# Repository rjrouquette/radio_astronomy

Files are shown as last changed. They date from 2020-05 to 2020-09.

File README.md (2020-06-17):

# Radio Astronomy
This project is an attempt at an SDR DAS phased-array radio astronomy system.  The intent is to produce a flexible and scalable system that can be easily repurposed with minimal additional cost.

## Digitizer
The digitizer board employs a direct IF to digital conversion toplogy to reduce the 62.5 MHz IF input into I+Q baseband data.

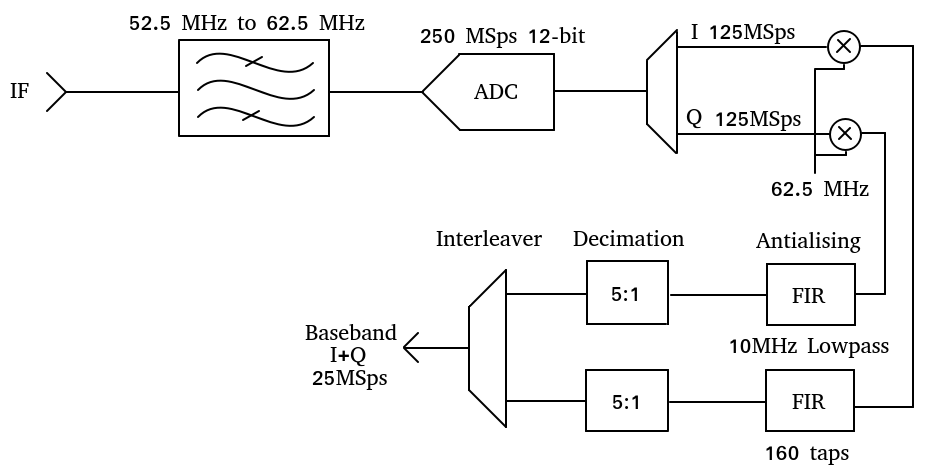
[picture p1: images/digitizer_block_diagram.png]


## Baseband Data
The SDR DAS modules will produce baseband I+Q samples at 25 MSps with 10 MHz for I, 10 MHz for Q, and a combined bandwidth of 20MHz.  The extra 2.5 MHz of Nyquist margin includes aliasing artifacts and may be utilized if degraded SNR is acceptable.  The 25 MSps I+Q data is formatted as two's complement 16-bit integers for both I and Q which yields a raw data bandwidth of 800 Mbps.  An FT601 USB 3.0 FIFO is used to offload the data.

## Master Clock
A master clock system will be employed to minimize timming drift between the SDR DAS modules.  The master clock provides a BPSK encoded PPS signal on a 25 MHz carrier via coax.  The rising edge of the PPS signal will be used to synchronize sample framing and PLL counters to minimuze phase errors and relative drift.  The master clock source is GPS disciplined to reduce frequency drift and absolute offset errors.  A plot of the GPSDO PLL performance is provided below.  The GPS antenna is currently located indoors.  The PLL Error and RMS Error values are the mean and RMS computed over a trailing 64s window by the on-board microntroller.  The two "Mean" dials on the right show the average values over the full 12 hour span.

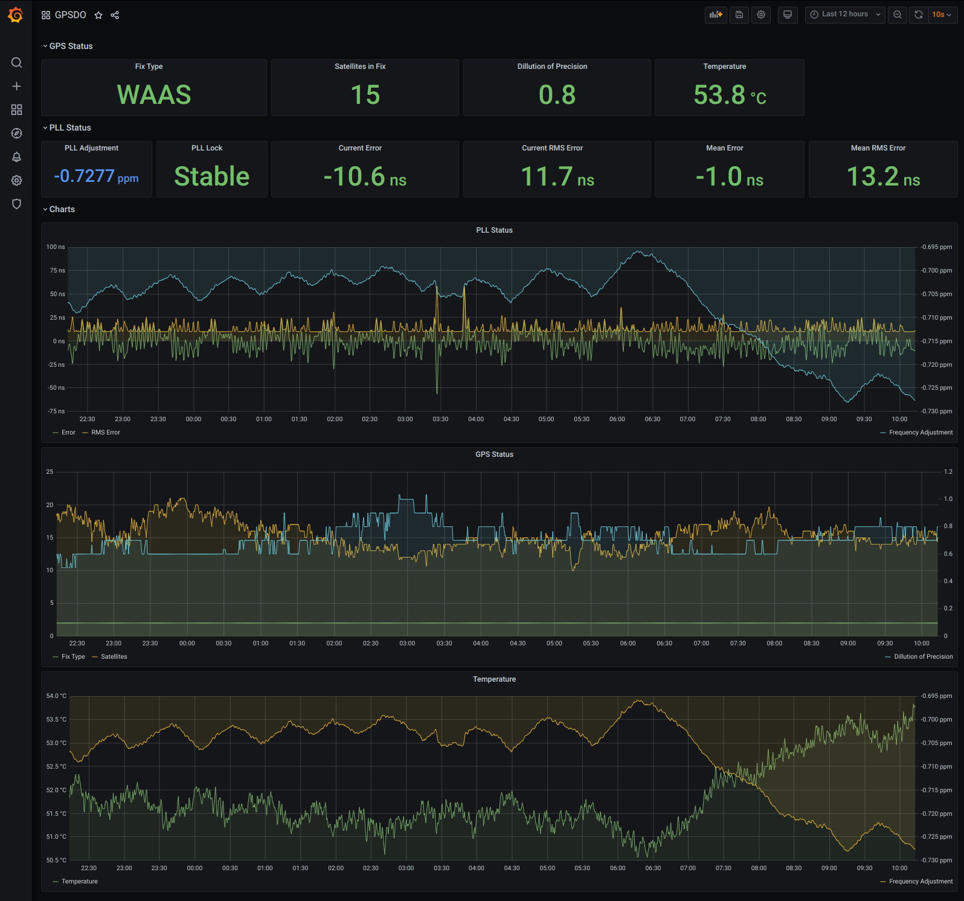
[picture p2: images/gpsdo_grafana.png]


## Slave Clock
The slave clock BPSK receivers use digital Costas loops to synchronize SiT 3808 25 MHz VCXOs to the GPSDO.  The receivers provide both clock and PPS recovery and introduce less than 1 ppb of additional phase noise.

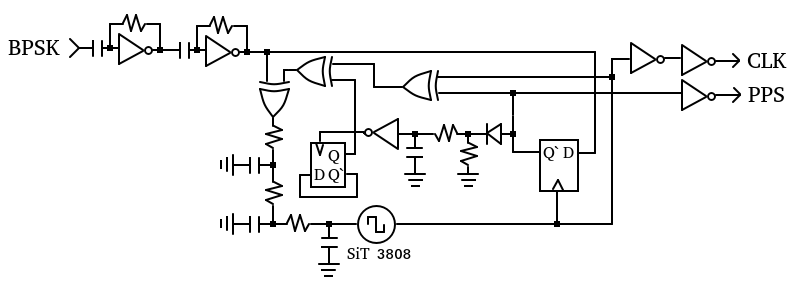
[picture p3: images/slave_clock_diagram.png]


[digitzer]: https://github.com/rjrouquette/radio_astronomy/raw/master/images/digitizer_block_diagram.png "Block Diagram"
[gpsdo]: https://github.com/rjrouquette/radio_astronomy/raw/master/images/gpsdo_grafana.png "GPSDO Performance"
[slave_clock]: https://github.com/rjrouquette/radio_astronomy/raw/master/images/slave_clock_diagram.png "Block Diagram"

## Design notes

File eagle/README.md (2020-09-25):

# EAGLE Board Layout Files
The board layouts for the various sub modules are loacted here.

## Antenna
The antenna boards are dual-polarized patch antennas with diversity outputs.  The patch antennas are matched to 50 Ohms using a microstrip line and inductor.

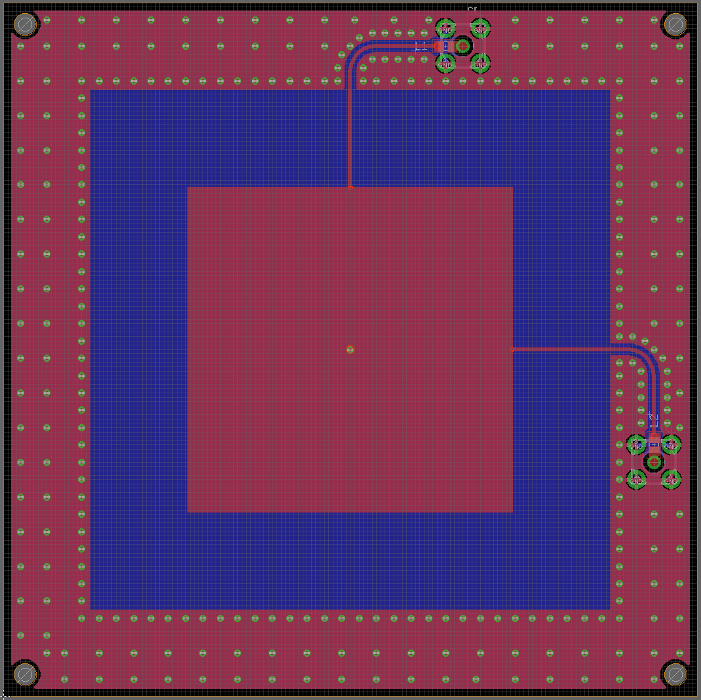
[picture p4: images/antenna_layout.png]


## Master Clock (GPSDO)
The master clock board is based around the STMicro TESEO-LIV3R GPS module and a SiTime SIT3807 VCXO.  The board injects 3.3 V into the 50 Ohm GPS SMA connector to support active antennas.  The reference clock BPSK output signals are available through four 50 Ohm SMA connectors.  Power is supllied to the board either through a micro USB connector or wire holes.  An ATXMega16A4U and discrete logic form the basis of the GPSDO PLL and BPSK transmitter.  The XMega DAC output passes through a 6.3 second RC low-pass filter before entring the control pin on the VCXO.

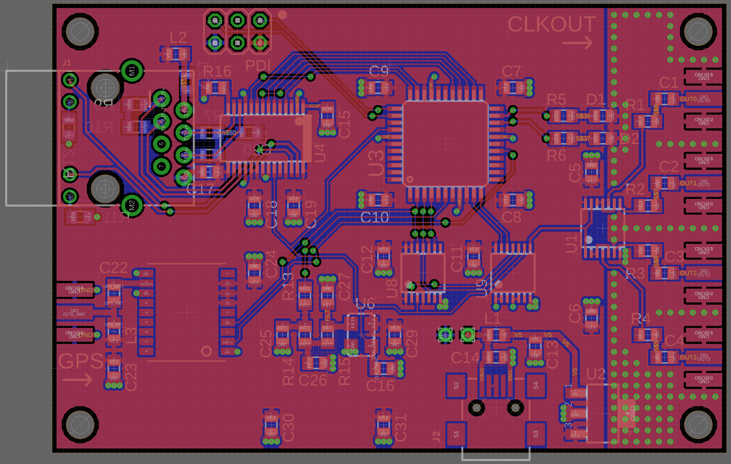
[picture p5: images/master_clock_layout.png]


## Slave Clock (GPSDO)
The slave clock board is based around the SiTime SIT3808 VCXO and provides both clock and PPS recovery.

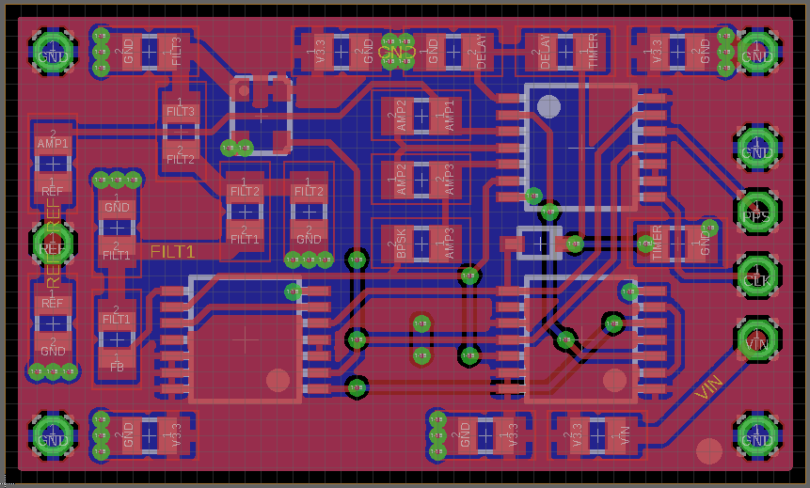
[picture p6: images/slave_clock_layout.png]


[antenna]: https://github.com/rjrouquette/radio_astronomy/raw/master/images/antenna_layout.png "Antenna Layout"
[clk_master]: https://github.com/rjrouquette/radio_astronomy/raw/master/images/master_clock_layout.png "Master Clock Layout"
[clk_slave]: https://github.com/rjrouquette/radio_astronomy/raw/master/images/slave_clock_layout.png "Slave Clock Layout"

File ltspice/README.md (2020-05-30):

# LTSpice Files
Collection of various LTSpice simulation files.

## Antenna Files
* antenna_lna.asc

## Receiver Files
* ltc5566_matching_374MHz.asc

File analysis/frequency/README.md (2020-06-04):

# Rudimentary Frequency Domain Analysis
Basic time-series simulation for estimation frequency response and alias rejection of mixers.  Perform simple IIR and FIR tasks as well simulate ADC sampling and Nyquist aliasing.

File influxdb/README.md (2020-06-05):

# InfluxDB Data Collectors
Collection of scripts and systemd wrappers to collect record statistics to influxdb.

## GPSDO
Requests and records data from the micro webserver on the master clock board.  The python script requires python3.

The files should be installed as follows:
* gpsdo.py -> /usr/local/bin/gpsdo.py
* gpsdo.service -> /etc/systemd/system/ (can also go to one of the alternate systemd directories)

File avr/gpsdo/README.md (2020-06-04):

# GPSDO Firmware
Atmel XMega16A4U source code for PPS generation, GPS PLL, and UDP status engine.  This code uses the [tuxgraphics.org](http://tuxgraphics.org/electronics/200611/embedded-webserver.shtml) ENC28J60 webserver source code.

The uC generates its own PPS signal for comparison with the GPS PPS signal by cascading two of the 16-bit counters to fully divide the 25 MHz clock into one second intervals and an external XOR gate to combine the timer comparison outputs.  The phase alignment between the two PPS signals is performed using an external D-type flip-flop that captures the GPS PPS level on the rising edge of the uC PPS signal.

The uC closes the PPS PLL by using the external phase comparison to increment/decrement the DAC output level.  Additional loop stability improvements such as PPS edge stepping and a dynamic update interval are implemented in software to improve settling time and reduce oscillations.

Tracking statistics are also collected using an additional 16-bit timer to capture the relative timing of the two PPS sigmals.  This information is accessible via the UDP network interface.

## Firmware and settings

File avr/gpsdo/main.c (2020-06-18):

#include <avr/io.h>
#include <avr/interrupt.h>
#include <stdio.h>
#include <stdlib.h>
#include <string.h>
#include <util/delay.h>

#include "gpsdo.h"
#include "leds.h"
#include "nop.h"
#include "net/enc28j60.h"
#include "net/ip_arp_udp_tcp.h"
#include "net/dhcp_client.h"

#define LEDON ledOn(LED1)
#define LEDOFF ledOff(LED1)

// interface MAC address
uint8_t macAddr[6] = {0x54, 0x55, 0x58, 0x10, 0x00, 0x29};
//uint8_t macAddr[6] = { 0xa0, 0x36, 0x9f, 0x00, 0x00, 0x00 };
// My own IP (DHCP will provide a value for it):
static uint8_t myip[4]={0,0,0,0};
// Default gateway (DHCP will provide a value for it):
static uint8_t gwip[4]={0,0,0,0};
#define TRANS_NUM_GWMAC 1
static uint8_t gwmac[6]={0,0,0,0,0,0};
// Netmask (DHCP will provide a value for it):
static uint8_t netmask[4]={0,0,0,0};

// packet buffer
#define BUFFER_SIZE 650
static uint8_t buf[BUFFER_SIZE+1];

// gps NEMA buffer, record zero is rx buffer
static volatile uint8_t dateTimeReady = 0;
static volatile uint8_t rx_cnt = 0;
char gpsMsgs[4][83];

void initSysClock(void);
void sendGpsConfig(const char *pstr);
uint32_t appendSimpleHash(uint8_t byte, uint32_t hash);
void initMacAddress();
void arpresolver_result_callback(uint8_t *ip __attribute__((unused)),uint8_t reference_number,uint8_t *mac);

uint16_t http200ok(void) {
    return fill_tcp_data_p(
            buf,
            0,
            PSTR("HTTP/1.0 200 OK\r\nContent-Type: text/plain\r\nPragma: no-cache\r\n\r\n")
    );
}

// prepare the webpage by writing the data to the tcp send buffer
uint16_t print_webpage(uint8_t *buf) {
    // snapshot pll status
    uint8_t locked = isPllLocked();
    float error = getPllError();
    float errRms = getPllErrorRms();
    float fdbk = getPllFeedback();
    float temperature = getPllTemperature();

    char temp[16];
    uint16_t plen;
    plen = http200ok();

    plen = fill_tcp_data_p(buf, plen, PSTR("Temperature: "));
    sprintf(temp, "%.1f", temperature);
    plen = fill_tcp_data(buf, plen, temp);

    plen = fill_tcp_data_p(buf, plen, PSTR(" C\nPLL Stable: "));
    plen = fill_tcp_data_p(buf, plen, locked ? PSTR("yes") : PSTR("no"));

    plen = fill_tcp_data_p(buf, plen, PSTR("\nPLL Error: "));
    sprintf(temp, "%.1f", error);
    plen = fill_tcp_data(buf, plen, temp);

    plen = fill_tcp_data_p(buf, plen, PSTR(" ns\nPLL RMSE: "));
    sprintf(temp, "%.1f", errRms);
    plen = fill_tcp_data(buf, plen, temp);

    plen = fill_tcp_data_p(buf, plen, PSTR(" ns\nPLL Offset: "));
    sprintf(temp, "%.4f", fdbk);
    plen = fill_tcp_data(buf, plen, temp);

    plen = fill_tcp_data_p(buf, plen, PSTR(" ppm\nGPS NEMA:\n"));
    plen = fill_tcp_data(buf, plen, gpsMsgs[1]);
    plen = fill_tcp_data(buf, plen, gpsMsgs[2]);
    plen = fill_tcp_data(buf, plen, gpsMsgs[3]);
    plen = fill_tcp_data(buf, plen, "\n");
    return plen;
}

int main(void) {
    cli();
    initLEDs();
    initSysClock();
    initGPSDO();

    // init USART for 9600 baud (bsel = 649, bscale = -1)
    USARTC1.BAUDCTRLA = 0x89u;
    USARTC1.BAUDCTRLB = 0xf2u;
    USARTC1.CTRLA = 0x10u;
    USARTC1.CTRLC = 0x03u;
    USARTC1.CTRLB = 0x10u;
    // set PPS clock frequency to 64MHz
    sendGpsConfig(PSTR("$PSTMSETPAR,1197,64*17\r\n"));
    // disable low power mode
    sendGpsConfig(PSTR("$PSTMSETPAR,1200,0x80000000,2*46\r\n"));
    // disable low power mode
    sendGpsConfig(PSTR("$PSTMCFGLPA,0,1,1,1,8,60,180,0,0,15,9,7000*39\r\n"));

    // startup complete
    PMIC.CTRL = 0x07u; // enable all interrupts
    sei();

    uint16_t dat_p,plen;
    uint8_t rval;

    // init ethernet controller
    initMacAddress();
    enc28j60Init(macAddr);

    /* Magjack leds configuration, see enc28j60 datasheet, page 11 */
    // LEDB=green LEDA=yellow
    //
    // 0x476 is PHLCON LEDA=links status, LEDB=receive/transmit
    // enc28j60PhyWrite(PHLCON,0b0000 0100 0111 01 10);
    enc28j60PhyWrite(PHLCON,0x476);

    LEDON;
    // DHCP handling. Get the initial IP
    rval=0;
    init_mac(macAddr);
    while(rval==0){
        plen=enc28j60PacketReceive(BUFFER_SIZE, buf);
        buf[BUFFER_SIZE]=0;
        rval=packetloop_dhcp_initial_ip_assignment(buf,plen,macAddr[0]);
    }
    // we have an IP:
    dhcp_get_my_ip(myip,netmask,gwip);
    client_ifconfig(myip,netmask);
    LEDOFF;

    // pause for a bit
    _delay_ms(100);

    LEDON;
    // we have a gateway.
    // find the mac address of the gateway (e.g your dsl router).
    get_mac_with_arp(gwip,TRANS_NUM_GWMAC,&arpresolver_result_callback);
    while(get_mac_with_arp_wait()){
        // to process the ARP reply we must call the packetloop
        plen=enc28j60PacketReceive(BUFFER_SIZE, buf);
        packetloop_arp_icmp_tcp(buf,plen);
    }
    LEDOFF;

    // infinite loop
    for(;;) {
        plen=enc28j60PacketReceive(BUFFER_SIZE, buf);
        buf[BUFFER_SIZE]='\0'; // http is an ascii protocol. Make sure we have a string terminator.

        // DHCP renew IP:
        plen=packetloop_dhcp_renewhandler(buf,plen); // for this to work you have to call dhcp_6sec_tick() every 6 sec
        dat_p=packetloop_arp_icmp_tcp(buf,plen);

        // dat_p will be unequal to zero if there is a valid  http get
        if(dat_p==0){
            // no http request
            if (enc28j60linkup()) {
                LEDON;
            } else {
                LEDOFF;
            }
            continue;
        }

        // tcp port 80 begin
        LEDOFF;
        if (strncmp("GET ",(char *)&(buf[dat_p]),4)!=0) {
            // head, post and other methods:
            dat_p=http200ok();
            dat_p=fill_tcp_data_p(buf,dat_p,PSTR("<h1>200 OK</h1>"));
            www_server_reply(buf,dat_p);
        }
        // just one web page in the "root directory" of the web server
        else if (strncmp("/ ",(char *)&(buf[dat_p+4]),2)==0) {
            dat_p=print_webpage(buf);
            www_server_reply(buf,dat_p);
        }
        else {
            dat_p=fill_tcp_data_p(buf,0,PSTR("HTTP/1.0 401 Unauthorized\r\nContent-Type: text/html\r\n\r\n<h1>401 Unauthorized</h1>"));
            www_server_reply(buf,dat_p);
        }
    }

    return 0;
}

// configure xmega to run at 50 MHz
void initSysClock(void) {
    // drop down to 2MHz clock before changing PLL settings
    CCP = CCP_IOREG_gc;
    CLK.CTRL = CLK_SCLKSEL_RC2M_gc; // Select 2MHz RC OSC
    nop4();

    OSC.XOSCCTRL = OSC_XOSCSEL_EXTCLK_gc;
    OSC.CTRL |= OSC_XOSCEN_bm;
    while(!(OSC.STATUS & OSC_XOSCRDY_bm)); // wait for external clock ready

    CCP = CCP_IOREG_gc;
    OSC.XOSCFAIL = 0x01u; // enable interrupt on clock failure
    nop4();

    // configure PLL
    OSC.PLLCTRL = 0xc2u; // external clock x2
    OSC.CTRL |= OSC_PLLEN_bm;
    while(!(OSC.STATUS & OSC_PLLRDY_bm)); // wait for pll ready

    CCP = CCP_IOREG_gc;
    CLK.PSCTRL = CLK_PSADIV_1_gc; // divide by 1
    nop4();

    CCP = CCP_IOREG_gc;
    CLK.CTRL = CLK_SCLKSEL_PLL_gc; // Select PLL
    nop4();
}

ISR(OSC_OSCF_vect) {
    // reset xmega
    cli();
    CCP = 0xD8;
    RST.CTRL = RST_SWRST_bm;
}

uint32_t appendSimpleHash(uint8_t byte, uint32_t hash) {
    return ((hash) << 5u) + (hash) + byte;
}

uint8_t readProdByte(const volatile uint8_t *offset) {
    NVM.CMD = NVM_CMD_READ_CALIB_ROW_gc;
    uint8_t temp = pgm_read_byte(offset);
    NVM.CMD = NVM_CMD_NO_OPERATION_gc;
    return temp;
}

void initMacAddress() {
    // create hash of serial number
    uint32_t hash = 5381;
    hash = appendSimpleHash(readProdByte(&PRODSIGNATURES_LOTNUM0), hash);
    hash = appendSimpleHash(readProdByte(&PRODSIGNATURES_LOTNUM1), hash);
    hash = appendSimpleHash(readProdByte(&PRODSIGNATURES_LOTNUM2), hash);
    hash = appendSimpleHash(readProdByte(&PRODSIGNATURES_LOTNUM3), hash);
    hash = appendSimpleHash(readProdByte(&PRODSIGNATURES_LOTNUM4), hash);
    hash = appendSimpleHash(readProdByte(&PRODSIGNATURES_LOTNUM5), hash);
    hash = appendSimpleHash(readProdByte(&PRODSIGNATURES_WAFNUM), hash);
    hash = appendSimpleHash(readProdByte(&PRODSIGNATURES_COORDX0), hash);
    hash = appendSimpleHash(readProdByte(&PRODSIGNATURES_COORDX1), hash);
    hash = appendSimpleHash(readProdByte(&PRODSIGNATURES_COORDY0), hash);
    hash = appendSimpleHash(readProdByte(&PRODSIGNATURES_COORDY1), hash);

    // use lower 24-bits as last 24-bits of MAC address
    macAddr[5] = (hash >> 0u) & 0xffu;
    macAddr[4] = (hash >> 8u) & 0xffu;
    macAddr[3] = (hash >> 16u) & 0xffu;
}

// the __attribute__((unused)) is a gcc compiler directive to avoid warnings about unsed variables.
void arpresolver_result_callback(uint8_t *ip __attribute__((unused)),uint8_t reference_number,uint8_t *mac){
    uint8_t i=0;
    if (reference_number==TRANS_NUM_GWMAC){
        // copy mac address over:
        while(i<6){gwmac[i]=mac[i];i++;}
    }
}

ISR(USARTC1_RXC_vect, ISR_NOBLOCK) {
    uint8_t byte = USARTC1.DATA;
    if(byte == '$') {
        rx_cnt = 0;
    }
    else if(rx_cnt >= 82) {
        return;
    }

    // save byte
    gpsMsgs[0][rx_cnt++] = byte;

    // end-of-message
    if(byte == '\n') {
        gpsMsgs[0][rx_cnt] = 0;

        if(strncmp(gpsMsgs[0], "$GPGGA,", 7) == 0) {
            strcpy(gpsMsgs[1], gpsMsgs[0]);
        }
        else if(strncmp(gpsMsgs[0], "$GNGSA,", 7) == 0) {
            strcpy(gpsMsgs[2], gpsMsgs[0]);
        }
        else if(strncmp(gpsMsgs[0], "$GPRMC,", 7) == 0) {
            strcpy(gpsMsgs[3], gpsMsgs[0]);
            dateTimeReady = 1u;
        }
    }
}

void sendGpsConfig(const char *pstr) {
    for(;;) {
        char byte = pgm_read_byte(pstr++);
        if(byte == 0) break;
        while(!(USARTC1.STATUS & 0x20u)) nop();
        USARTC1.DATA = byte;
    }
}

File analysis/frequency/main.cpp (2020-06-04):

#include <iostream>
#include <cmath>
#include <list>
#include <fftw3.h>
#include "sine.h"
#include "mixer.h"
#include "fir.h"

using namespace std;

#define FFT_SIZE (8192)

#define SAMP_FREQ (250.0)
#define ADC_SAMPLES (1024 + FFT_SIZE * 10)
#define OVERSAMPLING (20)
#define SAMPLES (ADC_SAMPLES * OVERSAMPLING)

#define FREQ_LO1 (1413.0 - 374.0)
#define FREQ_LO2 (374.0 + 62.5)

extern double fir_5GSps_374MHz[993];
extern double fir_5GSps_100MHz_LP[512];
extern double fir_decimation[160];

void createSignalChain(std::list<module *> &signalChain, double freqRf, double freqSamp);
void toPolar(double x, double y, double &mag, double &angle);

int main(int argc, char **argv) {
    std::list<module *> signalChain;
    createSignalChain(signalChain, 1403.0, SAMP_FREQ * OVERSAMPLING);

    double output[ADC_SAMPLES];
    for(unsigned i = 0; i < SAMPLES; i++) {
        for(auto m : signalChain)
            m->doStep();

        if(((i+1) % OVERSAMPLING) == 0) {
            output[i / OVERSAMPLING] = signalChain.back()->getOutput().getValue() * 4;
        }
    }

    // multiply IQ samples by Nyquist frequency
    for(unsigned i = 0; i < ADC_SAMPLES; i++) {
        if((i % 4) >= 2)
            output[i] = -output[i];
    }

    // FIR decimation filter
    for(unsigned i = ADC_SAMPLES - 1; i >= 320; i--) {
        double acc = 0;
        for(unsigned j = 0; j < 160; j++) {
            acc += output[i - 2 * j] * fir_decimation[j];
        }
        output[i] = acc;
    }

    fftw_complex in[FFT_SIZE], out[FFT_SIZE];
    auto p = fftw_plan_dft_1d(FFT_SIZE, in, out, FFTW_FORWARD, FFTW_ESTIMATE);

    // split IQ samples
    for(unsigned i = 0; i < FFT_SIZE * 10; i += 10) {
        in[i / 10][0] = output[1024 + i + 0];
        in[i / 10][1] = output[1024 + i + 1];
    }

    fftw_execute(p);
    fftw_destroy_plan(p);

    std::list<std::pair<double, unsigned> > bins;
    double mag, angle;
    for(unsigned i = 0; i < FFT_SIZE; i++) {
        toPolar(out[i][0], out[i][1], mag, angle);
        bins.emplace_back(std::make_pair(mag, i));
    }
    bins.sort();

    auto it = bins.rbegin();
    for(int i = 0; i < 20; i++) {
        if(it->second <= FFT_SIZE / 2) {
            cout << 0.1*(SAMP_FREQ * it->second / FFT_SIZE) << ": " << 20*log10(it->first) << endl;
        } else {
            cout << 0.1*(-SAMP_FREQ * (FFT_SIZE - it->second) / FFT_SIZE) << ": " << 20*log10(it->first) << endl;
        }
        it++;
    }

    return 0;
}

void createSignalChain(std::list<module *> &signalChain, double freqRf, double freqSamp) {
    auto rf = new sine(2 * M_PI * freqRf / freqSamp, 0);
    signalChain.push_back(rf);

    auto lo1 = new sine(2 * M_PI * FREQ_LO1 / freqSamp, 0);
    signalChain.push_back(lo1);

    auto lo2 = new sine(2 * M_PI * FREQ_LO2 / freqSamp, 0);
    signalChain.push_back(lo2);

    auto mix1 = new mixer(rf->getOutput(), lo1->getOutput());
    signalChain.push_back(mix1);

    auto filtIf1 = new fir(mix1->getOutput(), fir_5GSps_374MHz, 993);
    signalChain.push_back(filtIf1);

    auto mix2 = new mixer(filtIf1->getOutput(), lo2->getOutput());
    signalChain.push_back(mix2);

    auto filtIf2 = new fir(mix2->getOutput(), fir_5GSps_100MHz_LP, 512);
    signalChain.push_back(filtIf2);
}

void toPolar(double x, double y, double &mag, double &angle) {
    mag = hypot(x, y);
    angle = atan2(y, x);
}

double fir_5GSps_374MHz[993] = {
        0.00011332202117192451,
        -0.0005221432427767063,
        -0.000057559512396906476,
        0.00002367049770974349,
        0.000016757446452180823,
        -0.000010463897989399443,
        -0.00003837583217806309,
        -0.00005844903164690353,
        -0.00006610194636945257,
        -0.000059678741530200945,
        -0.00004038978077647017,
        -0.000012030412542320975,
        0.000019682538237316023,
        0.0000481668351925072,
        0.00006724556002668526,
        0.00007239834284581495,
        0.00006180121926200945,
        0.00003687324796521261,
        0.000002202575951616028,
        -0.000035206031236493563,
        -0.00006725451628794086,
        -0.00008643485271542864,
        -0.00008754278121752675,
        -0.0000689836781035076,
        -0.00003344320925020373,
        0.000012367578185664633,
        0.00005889741601122066,
        0.00009568003699678925,
        0.00011363754303683227,
        0.00010723149206997724,
        0.0000760271304258067,
        0.000025190224757568904,
        -0.000035235032896592016,
        -0.00009226229737905838,
        -0.00013268460677629454,
        -0.0001460705803267991,
        -0.00012737843120549277,
        -0.00007850484347654064,
        -0.000008355190072375574,
        0.00006867253234700202,
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
};

double fir_5GSps_100MHz_LP[512] = {
        -0.000851054664778229,
        0.00009599597523330914,
        0.00009847476810478784,
        0.00010566815952361405,
        0.00011678875745540102,
        0.00013142395611639914,
        0.00014892378476060044,
        0.00016875874283414443,
        0.00019027413454091285,
        0.0002128664095315184,
        0.00023588007681075014,
        0.0002587007193708334,
        0.0002806841244895548,
        0.0003012122925352535,
        0.0003196544605113298,
        0.00033541957957560674,
        0.00034794004056799203,
        0.0003567135954673325,
        0.0003612884457187008,
        0.00036129098762903693,
        0.0003564137965790894,
        0.0003464408452946636,
        0.000331242594625433,
        0.00031079788618040453,
        0.0002851875321291815,
        0.0002546069465337752,
        0.00021935589065249836,
        0.00017984550243403547,
        0.00013658748606757524,
        0.00009019672629427846,
        0.000041376935133862806,
        -0.000009084218043015287,
        -0.0000603342568169856,
        -0.00011146582078375345,
        -0.00016153717849495125,
        -0.00020958460439812835,
        -0.000254644276510329,
        -0.0002957680985835182,
        -0.00033204737765976357,
        -0.000362630275910355,
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
};
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

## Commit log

2020-05-08 add board layouts
    [clk_master.brd, clk_slave.brd, sdr_rx.brd]
2020-05-12 add antenna board layout
    [antenna.brd]
2020-05-12 update eagle files
    [clk_master.brd, sdr_rx.brd]
2020-05-13 update silkscreen on antenna board
    [antenna.brd]
2020-05-13 clean up master clock board layout
    [clk_master.brd]
2020-05-13 clean up slave clock board layout
    [clk_slave.brd]
2020-05-19 add down-converter board layout
    [receiver.brd, sdr_rx.brd]
2020-05-26 cleaner antenna layout
    [antenna.brd]
2020-05-27 adjust LNA component values
    [antenna.brd]
2020-05-27 add image of antenna board layout
2020-05-28 cleanup master clock layout
    [clk_master.brd]
2020-05-28 add master clock component values
    [clk_master.brd]
2020-05-28 bug fix with modular arithmetic
    [gpsdo.c]
2020-05-29 fix issue with receiver board
    [receiver.brd]
2020-05-29 add power injection to receiver board
    [digitizer.brd, receiver.brd]
2020-05-29 tweak rf matching network
    [receiver.brd]
2020-05-29 fix saw filter matching
    [receiver.brd]
2020-05-30 preparig enc28j60 driver (wip)
2020-05-31 preparing enc28j60 driver (wip)
2020-06-01 fix en28j60 spi
    [clk_master.brd]
2020-06-01 name more signals on board layout
    [clk_master.brd]
2020-06-01 more accurate spice sim of antenna LNA
    [antenna.brd]
2020-06-02 enable gps usart (bug fix)
    [main.c]
2020-06-02 revert attempt at improved accuracy
    [gpsdo.c]
2020-06-03 update master clock layout image
    [clk_master.brd]
2020-06-03 update board layout readme
2020-06-04 marginally better antenna match
    [antenna.brd]
2020-06-06 fix rms error calculation
    [gpsdo.c]
2020-06-06 finer adjustment if RMS error is below 250 ns
    [gpsdo.c]
2020-06-06 reduce pll tracking error
    [gpsdo.c]
2020-06-06 fix offset in error calculation
    [gpsdo.c]
2020-06-08 update slave clock design
    [clk_slave.brd]
2020-06-08 reduce slave clock drift to <1Hz RMS
    [clk_slave.brd]
2020-06-08 change master clock oscillator footprint
    [clk_master.brd]
2020-06-09 specifiy VCTCXO part number
    [clk_master.brd]
2020-06-09 add temperature to gpsdo status
2020-06-09 add gpsdo temperature to status
2020-06-09 implement averaging of temperature reading
2020-06-09 fix bug in gpsdo temperature
    [gpsdo.c]
2020-06-09 cleanup silkscreen
    [clk_master.brd]
2020-06-09 characterize gpsdo pll low pass filter
2020-06-10 progress on digitizer layout
    [digitizer.brd]
2020-06-11 add poe power supply simulation
    [digitizer.brd]
2020-06-12 reduce dhcp timer ISR overhead
2020-06-12 reduce DAC twiddle frequency to imrpove stability
    [gpsdo.c]
2020-06-13 adjust gpsdo DAC filter values
2020-06-14 bug fix in sending gps config strings
    [main.c]
2020-06-14 disable gps low power mode
2020-06-16 PID tuning
2020-06-16 change precision of PID loop
2020-06-17 revert xmega overclocking (temperature stability issues)
    [gpsdo.c]
2020-06-17 reduce output phase noise
    [gpsdo.c]
2020-06-18 add PID constants for SiT 5156
2020-06-27 gpsdo board calibration
2020-06-30 correct slave clock circuit
2020-07-01 fix slave clock board layout
    [clk_slave.brd]
2020-07-01 add RS232 PPS adapter board layout
    [pps_rs232.brd]
2020-07-02 simulate microstrip filter
2020-07-02 add board layout for microwave characterization
    [test.brd]
2020-08-10 update patch antenna test board
    [patch_antenna.brd, patch_test.brd]
2020-08-20 add microstrip filter layout
    [filter.brd]
2020-09-07 reorganize eagle files
    [antenna.brd, filter.brd, patch_antenna.brd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]
2020-09-07 add lna board layout
    [lna.brd]
2020-09-07 update antenna layout image
2020-09-25 progress on digitizer board
    [digitizer.brd]
